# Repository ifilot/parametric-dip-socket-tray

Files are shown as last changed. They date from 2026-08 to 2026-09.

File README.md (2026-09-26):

# Parametric DIP and PLCC socket trays





Stackable 160 × 160 mm storage trays for standard spring-contact DIP sockets and
MPE M-PLCC 32 T and M-PLCC 44 T through-hole sockets. The DIP trays use
continuous channels; the PLCC trays use individual pin-protecting positions. All
trays share the same interlocking interface and universal lid.

## Features

- Eight supported DIP profiles, including slim and wide DIP-28 sockets
- Dedicated PLCC32 and PLCC44 trays with pin-protecting positions
- Automatic selection of narrow 300 mil or wide 600 mil geometry
- Central support ridges keep the socket pins above the tray floor
- Capacity calculated automatically from the socket dimensions
- Common interlocking interface allows every tray size to stack together
- Universal stackable lid fits every tray size
- 2 mm clearance above stored sockets in a stack
- Recessed size labels with optional two-colour inlays
- Ready-to-print STLs and small fit-test coupons
- Fully parametric OpenSCAD source

## Downloads

**[Download the parametric OpenSCAD
source](https://raw.githubusercontent.com/ifilot/parametric-dip-socket-tray/master/dip_socket_tray.scad)**
· **[Download the complete
project](https://github.com/ifilot/parametric-dip-socket-tray/archive/refs/heads/master.zip)**
· **[Download versioned
releases](https://github.com/ifilot/parametric-dip-socket-tray/releases)** ·
**[View automated
builds](https://github.com/ifilot/parametric-dip-socket-tray/actions/workflows/build-trays.yml)**

**[Download the universal lid
STL](https://raw.githubusercontent.com/ifilot/parametric-dip-socket-tray/master/exports/dip-socket-tray-lid.stl)**

| Socket | Tray | Two-colour label | Fit test |
| --- | --- | --- | --- |
| DIP-14 | [Download STL](https://raw.githubusercontent.com/ifilot/parametric-dip-socket-tray/master/exports/dip14-tray.stl) | [Download label](https://raw.githubusercontent.com/ifilot/parametric-dip-socket-tray/master/exports/dip14-label.stl) | [Download test](https://raw.githubusercontent.com/ifilot/parametric-dip-socket-tray/master/exports/dip14-fit-test.stl) |
| DIP-16 | [Download STL](https://raw.githubusercontent.com/ifilot/parametric-dip-socket-tray/master/exports/dip16-tray.stl) | [Download label](https://raw.githubusercontent.com/ifilot/parametric-dip-socket-tray/master/exports/dip16-label.stl) | [Download test](https://raw.githubusercontent.com/ifilot/parametric-dip-socket-tray/master/exports/dip16-fit-test.stl) |
| DIP-18 | [Download STL](https://raw.githubusercontent.com/ifilot/parametric-dip-socket-tray/master/exports/dip18-tray.stl) | [Download label](https://raw.githubusercontent.com/ifilot/parametric-dip-socket-tray/master/exports/dip18-label.stl) | [Download test](https://raw.githubusercontent.com/ifilot/parametric-dip-socket-tray/master/exports/dip18-fit-test.stl) |
| DIP-20 | [Download STL](https://raw.githubusercontent.com/ifilot/parametric-dip-socket-tray/master/exports/dip20-tray.stl) | [Download label](https://raw.githubusercontent.com/ifilot/parametric-dip-socket-tray/master/exports/dip20-label.stl) | [Download test](https://raw.githubusercontent.com/ifilot/parametric-dip-socket-tray/master/exports/dip20-fit-test.stl) |
| DIP-28 wide | [Download STL](https://raw.githubusercontent.com/ifilot/parametric-dip-socket-tray/master/exports/dip28-tray.stl) | [Download label](https://raw.githubusercontent.com/ifilot/parametric-dip-socket-tray/master/exports/dip28-label.stl) | [Download test](https://raw.githubusercontent.com/ifilot/parametric-dip-socket-tray/master/exports/dip28-fit-test.stl) |
| DIP-32 wide | [Download STL](https://raw.githubusercontent.com/ifilot/parametric-dip-socket-tray/master/exports/dip32-tray.stl) | [Download label](https://raw.githubusercontent.com/ifilot/parametric-dip-socket-tray/master/exports/dip32-label.stl) | [Download test](https://raw.githubusercontent.com/ifilot/parametric-dip-socket-tray/master/exports/dip32-fit-test.stl) |
| DIP-40 wide | [Download STL](https://raw.githubusercontent.com/ifilot/parametric-dip-socket-tray/master/exports/dip40-tray.stl) | [Download label](https://raw.githubusercontent.com/ifilot/parametric-dip-socket-tray/master/exports/dip40-label.stl) | [Download test](https://raw.githubusercontent.com/ifilot/parametric-dip-socket-tray/master/exports/dip40-fit-test.stl) |
| DIP-28 slim | [Download STL](https://raw.githubusercontent.com/ifilot/parametric-dip-socket-tray/master/exports/dip28-slim-tray.stl) | [Download label](https://raw.githubusercontent.com/ifilot/parametric-dip-socket-tray/master/exports/dip28-slim-label.stl) | [Download test](https://raw.githubusercontent.com/ifilot/parametric-dip-socket-tray/master/exports/dip28-slim-fit-test.stl) |
| PLCC-32 socket | [Download STL](https://raw.githubusercontent.com/ifilot/parametric-dip-socket-tray/master/exports/plcc32-socket-tray.stl) | [Download label](https://raw.githubusercontent.com/ifilot/parametric-dip-socket-tray/master/exports/plcc32-socket-label.stl) | [Download test](https://raw.githubusercontent.com/ifilot/parametric-dip-socket-tray/master/exports/plcc32-socket-fit-test.stl) |
| PLCC-44 socket | [Download STL](https://raw.githubusercontent.com/ifilot/parametric-dip-socket-tray/master/exports/plcc44-socket-tray.stl) | [Download label](https://raw.githubusercontent.com/ifilot/parametric-dip-socket-tray/master/exports/plcc44-socket-label.stl) | [Download test](https://raw.githubusercontent.com/ifilot/parametric-dip-socket-tray/master/exports/plcc44-socket-fit-test.stl) |

## Tray previews

| DIP-14 — 104 sockets | DIP-16 — 91 sockets |
| --- | --- |
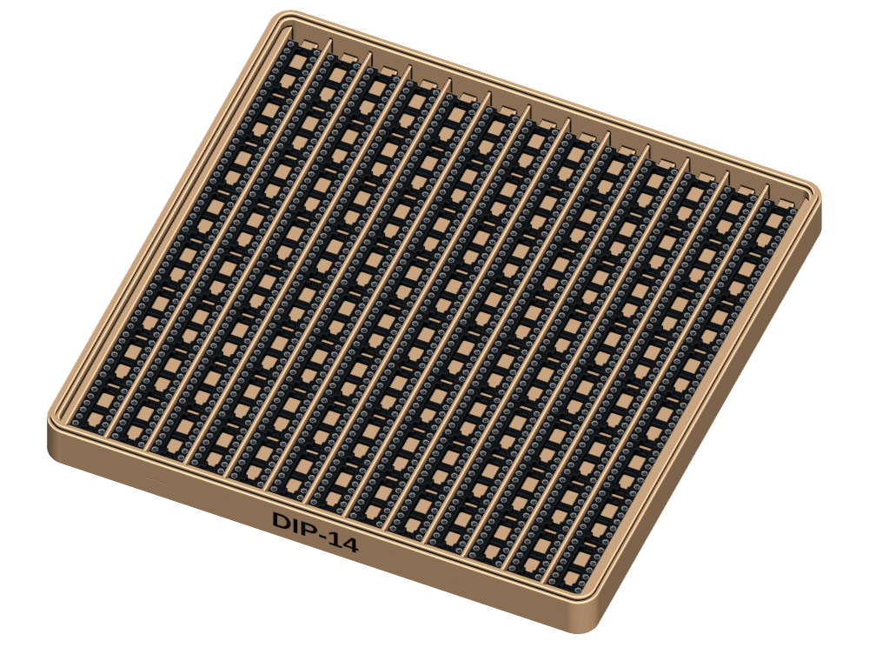
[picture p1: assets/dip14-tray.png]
DIP-14 tray
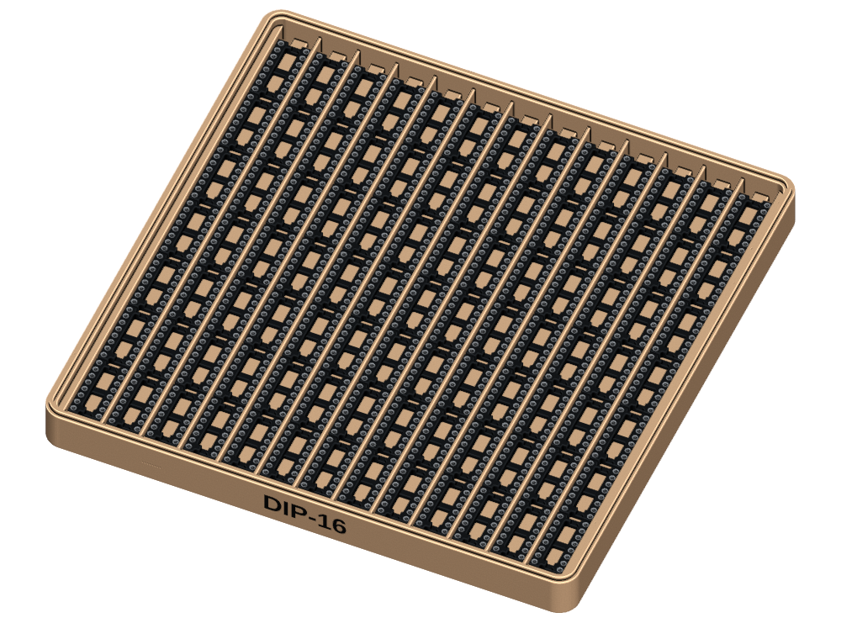
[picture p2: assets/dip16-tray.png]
DIP-16 tray
|  |  |

| DIP-18 — 78 sockets | DIP-20 — 65 sockets |
| --- | --- |
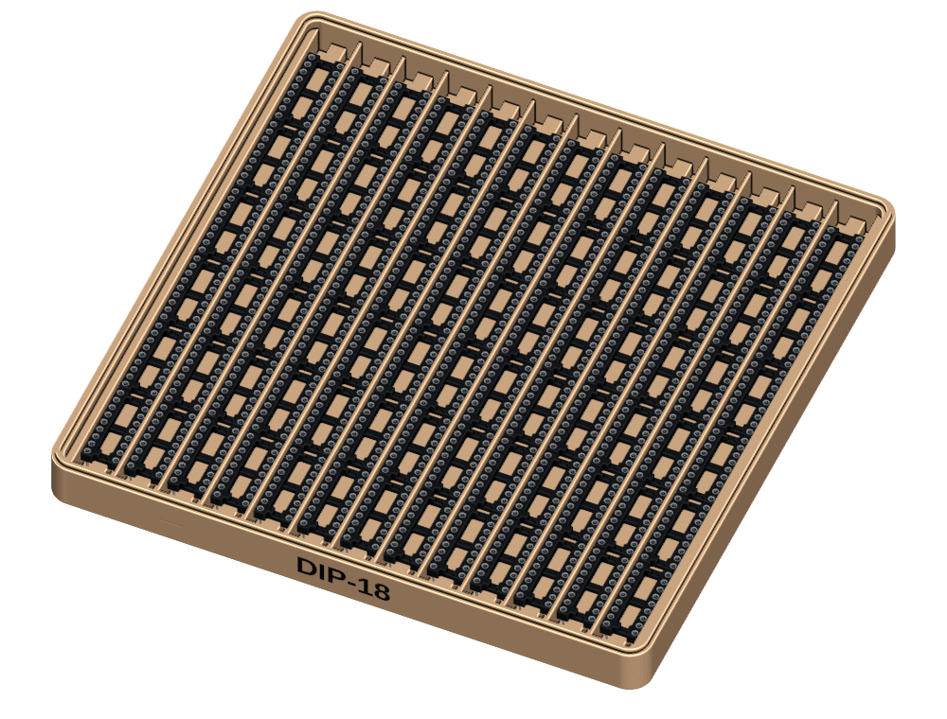
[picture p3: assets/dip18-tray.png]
DIP-18 tray
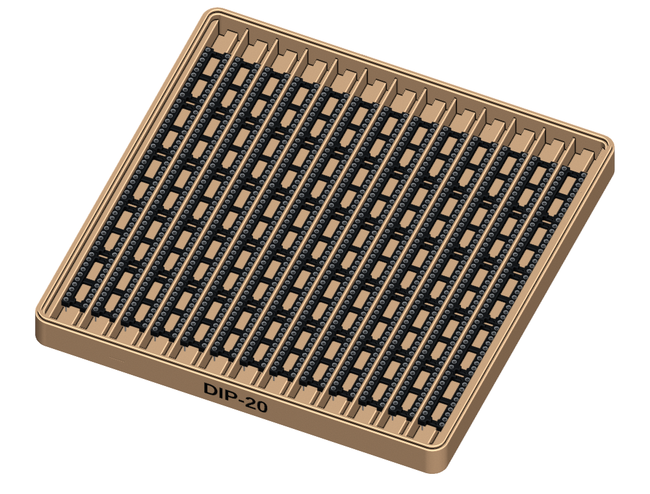
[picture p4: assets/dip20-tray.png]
DIP-20 tray
|  |  |

| DIP-28 wide — 32 sockets | DIP-32 wide — 24 sockets |
| --- | --- |
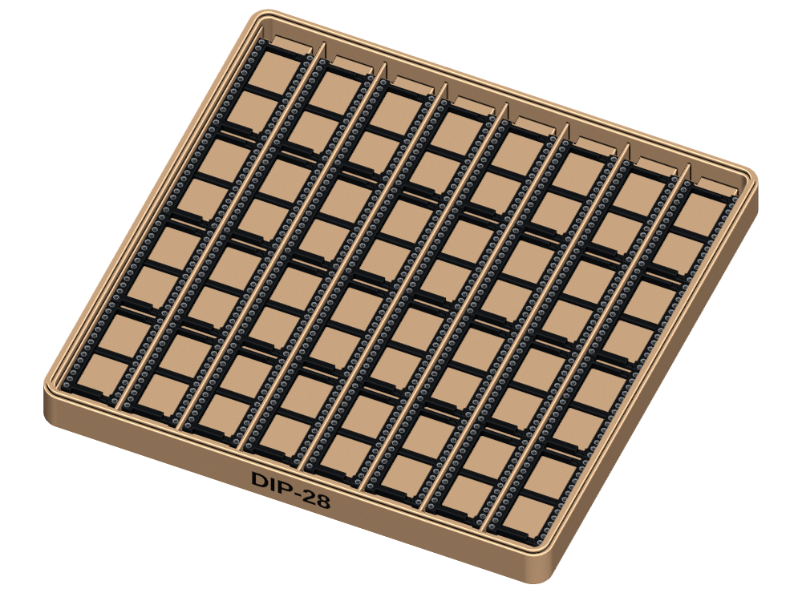
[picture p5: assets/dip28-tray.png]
Wide DIP-28 tray
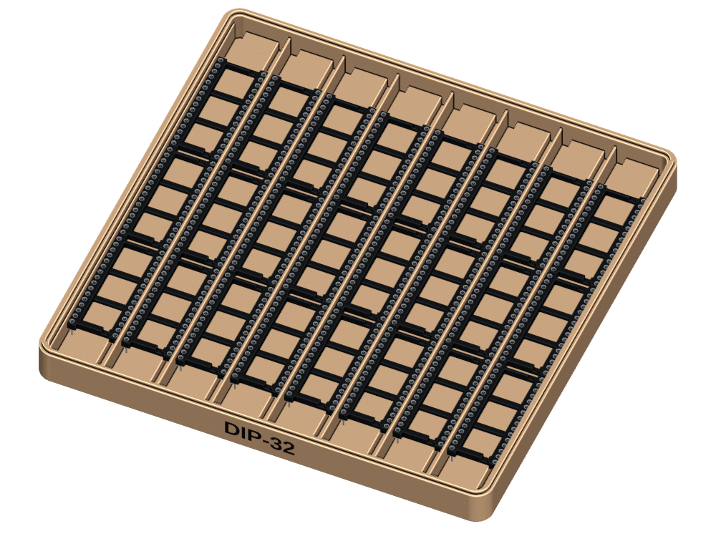
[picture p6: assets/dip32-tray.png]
Wide DIP-32 tray
|  |  |

| DIP-40 wide — 24 sockets |
| --- |
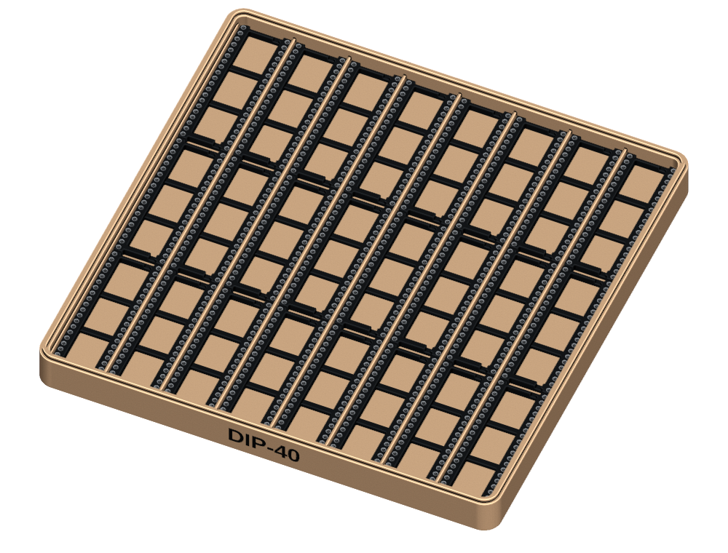
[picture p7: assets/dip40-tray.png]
Wide DIP-40 tray
|  |

| DIP-28 slim — 52 sockets | PLCC-44 socket — 36 sockets |
| --- | --- |
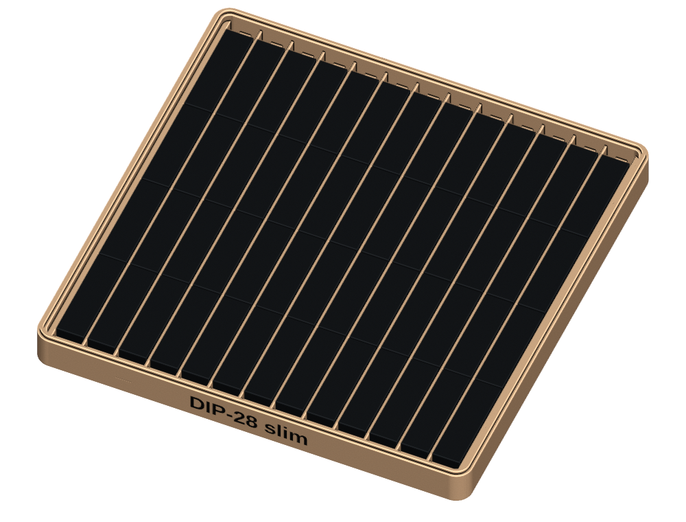
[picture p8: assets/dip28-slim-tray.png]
Slim DIP-28 tray
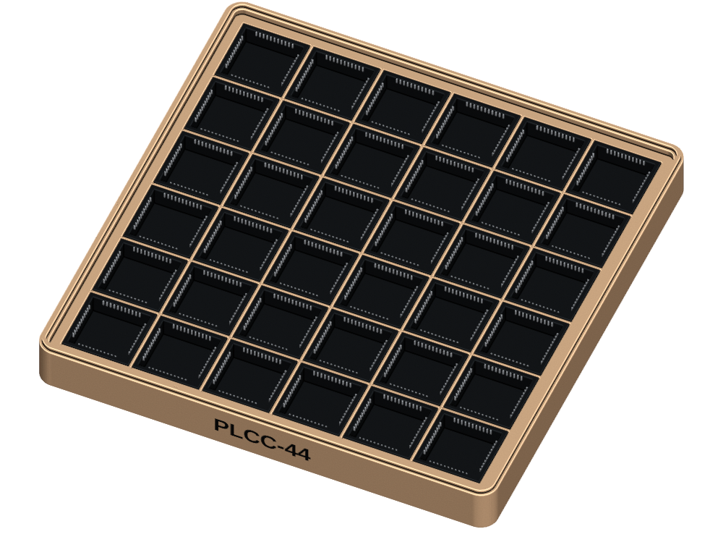
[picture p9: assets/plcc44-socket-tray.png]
PLCC-44 socket tray
|  |  |

| PLCC-32 socket — 49 sockets |
| --- |
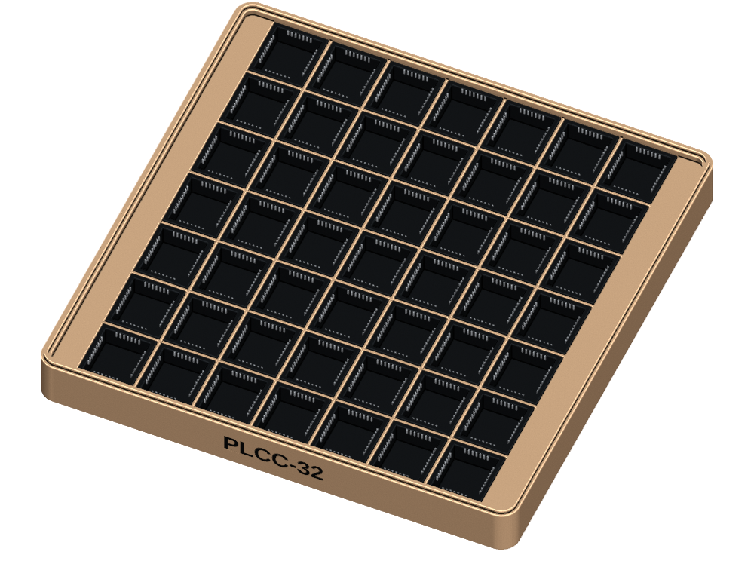
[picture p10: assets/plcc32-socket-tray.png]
PLCC-32 socket tray
|  |

The DIP socket geometry shown in the previews is derived from the [KiCad 3D
Models library](https://gitlab.com/kicad/libraries/kicad-packages3D), licensed
under [CC BY-SA 4.0 with the KiCad Libraries
Exception](https://www.kicad.org/libraries/license/). The PLCC32 and PLCC44
previews use simplified procedural models based on the MPE socket drawing. The
sockets are shown for illustration only and are not included in the downloadable
tray models.

## Supported trays

| Socket | Profile | Rows | Per row | Capacity |
| --- | --- | ---: | ---: | ---: |
| DIP-14 | 300 mil | 13 | 8 | 104 |
| DIP-16 | 300 mil | 13 | 7 | 91 |
| DIP-18 | 300 mil | 13 | 6 | 78 |
| DIP-20 | 300 mil | 13 | 5 | 65 |
| DIP-28 slim | 300 mil | 13 | 4 | 52 |
| DIP-28 wide | 600 mil | 8 | 4 | 32 |
| DIP-32 | 600 mil | 8 | 3 | 24 |
| DIP-40 | 600 mil | 8 | 3 | 24 |
| PLCC-32 socket | MPE series 300 | 7 | 7 | 49 |
| PLCC-44 socket | MPE series 300 | 6 | 6 | 36 |

Sockets lie end-to-end in long channels. Their plastic bodies rest on a central
ridge while both pin rows float in continuous trenches. The channel guides rise
4.2 mm above the support surface to keep sockets aligned.

The validated profiles use:

| Dimension | Narrow sockets | Wide sockets |
| --- | ---: | ---: |
| Pin-row spacing | 7.62 mm | 15.24 mm |
| Overall socket width | 10.16 mm | 17.78 mm |
| Central support ridge | 4.0 mm | 11.5 mm |

Socket length is derived from the 2.54 mm pin pitch and selected pin count.

The PLCC32 and PLCC44 models are based on the MPE series-300 entries in the [MPE
series-300
datasheet](https://cdn-reichelt.de/documents/datenblatt/C100/PLCC20_PLCC28_PLCC32_PLCC44~MPE.pdf).
Each socket rests on a central island while all four pin rows hang freely above
the tray floor. Shared guides keep the sockets separated and rise to
approximately the top of each socket body.

| PLCC socket dimension | PLCC32 | PLCC44 |
| --- | ---: | ---: |
| Body size (`B`) | 18.10 × 20.64 mm | 23.18 × 23.18 mm |
| Pin-row spacing (`D`) | 12.70 × 15.24 mm | 17.78 × 17.78 mm |
| Outer pin span (`A`) | 7.62 × 10.16 mm | 12.70 × 12.70 mm |
| Body height | 8.30 mm | 8.30 mm |
| Pin drop | 3.70 mm | 3.70 mm |
| Clear support footprint | 6.00 × 8.00 mm | 11.00 × 11.00 mm |
| Support height above tray floor | 4.00 mm | 4.00 mm |
| Guide height above support | 8.00 mm | 8.00 mm |

Dimension `D` is the PCB hole-row spacing; it does not specify the minimum clear
opening between the bent portions of the socket pins. The support footprints are
kept inside the nominal `A` pin spans. Their 4 mm height leaves 0.30 mm between
the nominal 3.70 mm pin tips and the tray floor. Print the fit test for the
exact socket before committing to the complete tray.

## Using the OpenSCAD model

Open `dip_socket_tray.scad` and set `pins` to one of:

```text
14, 16, 18, 20, 28, 32, 40
```

For the narrow 300 mil DIP-28 profile, also set `socket_profile = "narrow"`.

The profile is selected automatically by default; set `socket_profile` to
`narrow` for the slim DIP-28 tray. Use `part` to choose the output:

- `assembly` — preview the tray, contrasting label, and reference sockets
- `tray` — printable tray with recessed lettering
- `lid` — universal lid with a tray-compatible groove and stacking lip
- `label` — separate label inlay for two-colour printing
- `fit_test` — short channel for checking socket fit and pin clearance

The model prints the calculated tray capacity or lid dimensions in OpenSCAD's
console. Ready-to-print lid, tray, label, and fit-test STLs are available in
`exports/`.

For the PLCC socket trays, open `plcc32_socket_tray.scad` or
`plcc44_socket_tray.scad`. Each provides the same `part` choices and uses the
same stacking interface. Export it directly with, for example:

```sh
openscad -o plcc44-socket-tray.stl -D 'part="tray"' plcc44_socket_tray.scad
```

## Fit and customization

The DIP fit tests, including the slim DIP-28 profile, have been physically
verified with the intended socket styles. The PLCC44 fit test has also been
physically verified. The PLCC32 outer fit has been tested, while its revised
support island should still be confirmed with its fit test before printing the
complete tray. This is especially important for other socket brands or
constructions.

Useful parameters include:

- `narrow_socket_width`, `wide_socket_width`, and `side_clearance`
- `pin_drop` and `pin_clearance`
- `narrow_support_ridge_width` and `wide_support_ridge_width`
- `socket_height` and `vertical_clearance`
- `stack_fit` and `stack_groove_depth`
- `lid_thickness`

The PLCC32 and PLCC44 models additionally expose `socket_size`,
`pin_row_spacing`, `pin_span`, `support_size`, `support_height`, and its
independent guide clearances. Print the appropriate PLCC fit test before
committing to the complete tray, especially when using a socket from a different
manufacturer.

## Printing

Suggested PLA settings:

- 0.25 mm layer height
- Three perimeters
- 15–20% infill
- No supports

The printer must provide a build area of at least 160 × 160 mm.

## Building all parts

With OpenSCAD available on the command line, generate the universal lid plus all
30 tray, label, and fit-test STLs with:

```sh
bash scripts/build_all.sh
```

Output is written to `build/` by default. Pass a directory as the first argument
to use a different destination. GitHub Actions runs the same script for pushes
and pull requests that affect the model or build procedure, then publishes the
complete STL set as a downloadable workflow artifact.

## Versioning and releases

This project follows [Semantic Versioning](https://semver.org/). The current
version is recorded in [`VERSION`](VERSION), and release notes are maintained in
[`CHANGELOG.md`](CHANGELOG.md).

## Stacking interface

Every variant uses the same perimeter lip and underside groove:

| Feature | Dimension |
| --- | ---: |
| Lip width | 1.20 mm |
| Lip height | 1.20 mm |
| Groove width | 1.80 mm |
| Groove depth | 1.40 mm |
| Horizontal clearance | 0.30 mm per side |
| Vertical clearance inside groove | 0.20 mm |

The groove locates the upper tray while perimeter ledges carry its weight, so
the lip does not bottom out. All socket sizes can be stacked in any order. The
universal lid uses the same groove underneath and repeats the lip on top, so it
can cap a stack or sit between trays without breaking compatibility.

Export the lid directly with:

```sh
openscad -o dip-socket-tray-lid.stl -D 'part="lid"' dip_socket_tray.scad
```

## Two-colour labels

Export the tray and label separately:

```sh
openscad -o dip14-tray.stl -D 'pins=14' -D 'part="tray"' dip_socket_tray.scad
openscad -o dip14-label.stl -D 'pins=14' -D 'part="label"' dip_socket_tray.scad
```

Import the matching tray and label STLs into a multi-material slicer as parts of
the same object. Keep both at their original coordinates, then assign each part
to the desired material or colour. Do not auto-arrange the parts separately.

For single-colour printing, export only `tray`; the label remains recessed.

## License

This open hardware design is licensed under the CERN Open Hardware Licence
Version 2 — Strongly Reciprocal (`CERN-OHL-S-2.0`). You may use, modify,
manufacture, and sell products based on it under the terms in `LICENSE`.
Distributed modifications and products must retain the required notices and make
the corresponding complete source available.

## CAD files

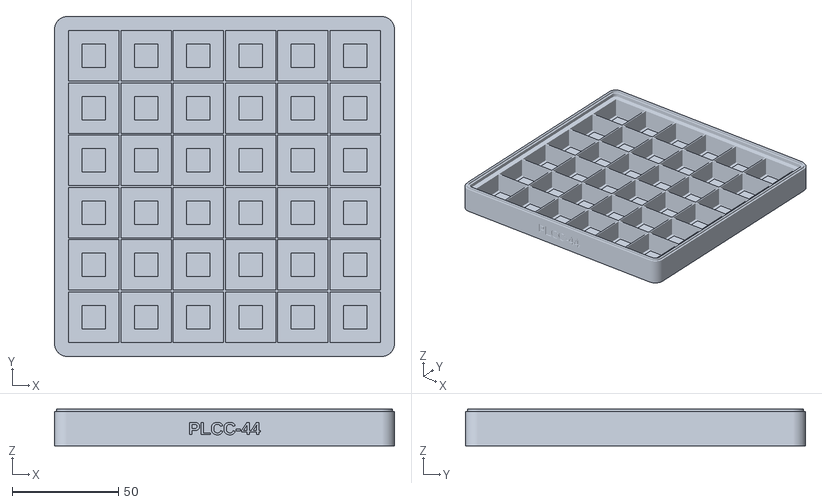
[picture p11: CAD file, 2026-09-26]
exports/plcc44-socket-tray.stl
160.0 x 160.0 x 17.3

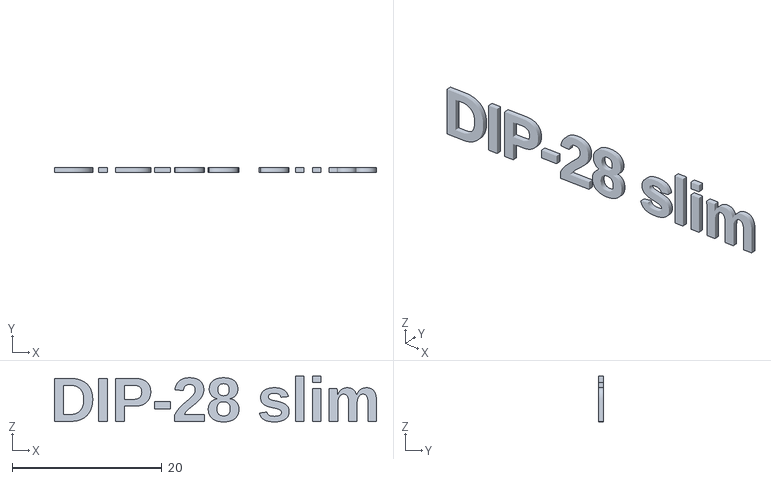
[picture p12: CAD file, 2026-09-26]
exports/dip28-slim-label.stl
43.0 x 0.62 x 6.12

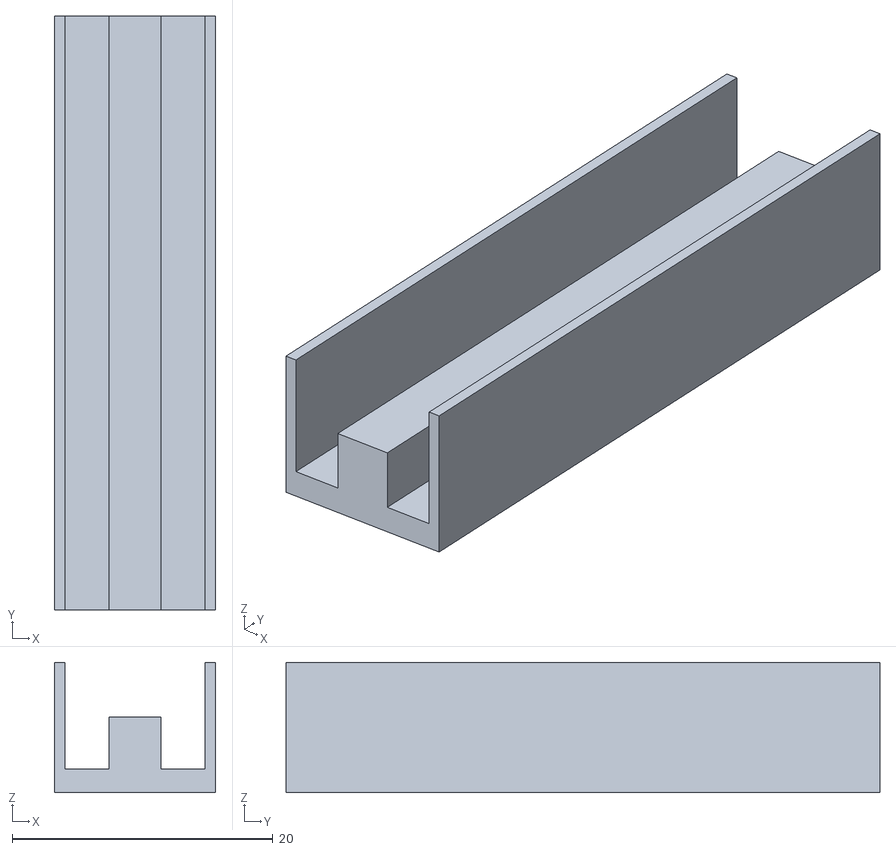
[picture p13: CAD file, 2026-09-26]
exports/dip28-slim-fit-test.stl
12.4 x 45.6 x 10.0

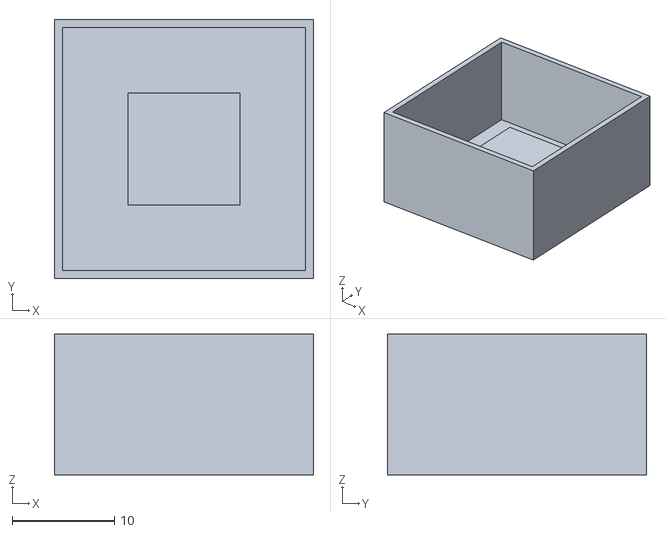
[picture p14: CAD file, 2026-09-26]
exports/plcc44-socket-fit-test.stl
25.4 x 25.4 x 13.8

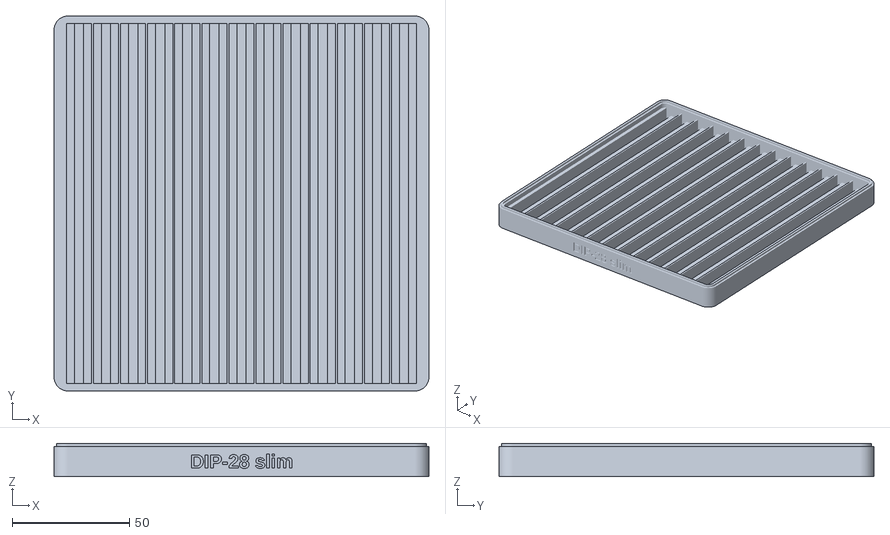
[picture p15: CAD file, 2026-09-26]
exports/dip28-slim-tray.stl
160.0 x 160.0 x 14.1

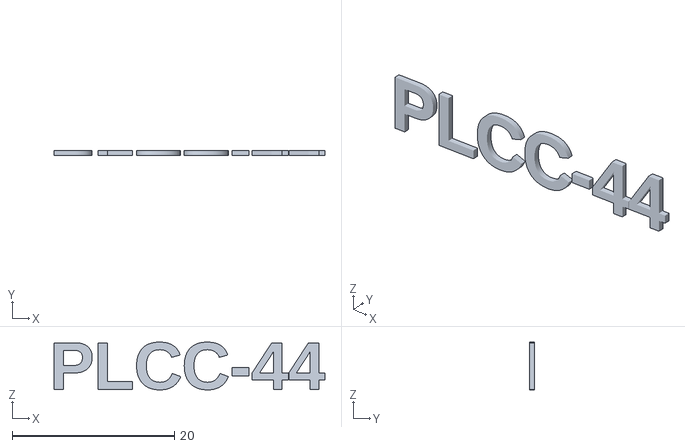
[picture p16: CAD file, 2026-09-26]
exports/plcc44-socket-label.stl
33.4 x 0.62 x 5.90

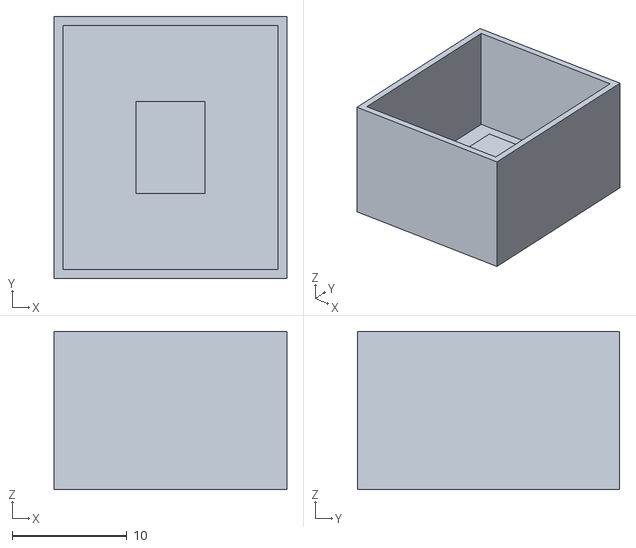
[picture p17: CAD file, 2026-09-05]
exports/plcc32-socket-fit-test.stl
20.3 x 22.8 x 13.8

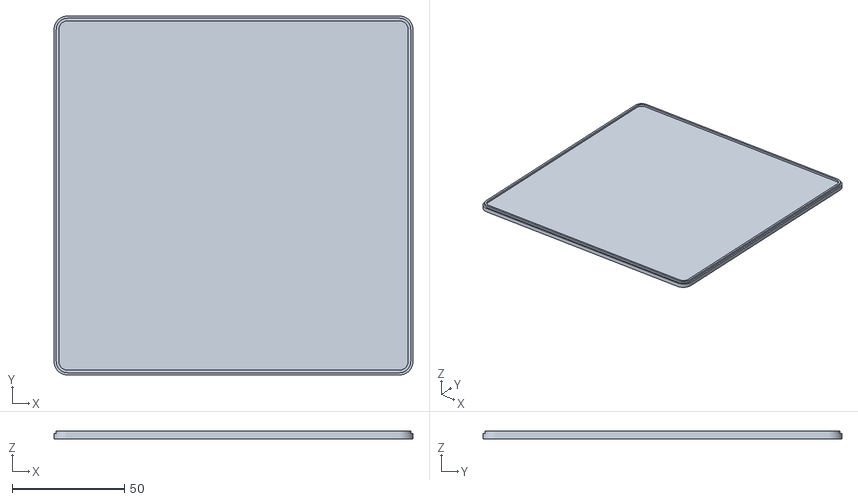
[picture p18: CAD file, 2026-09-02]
exports/dip-socket-tray-lid.stl
160.0 x 160.0 x 3.60

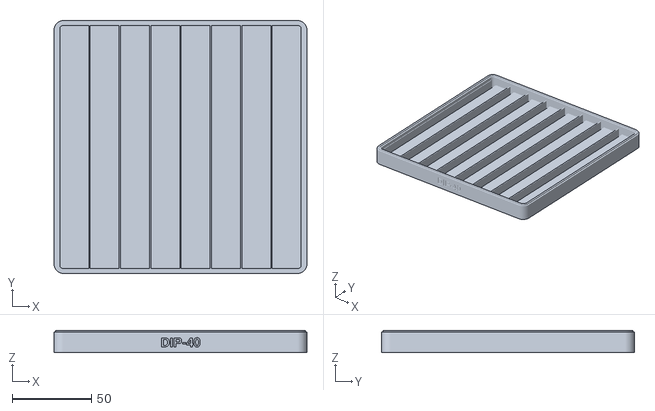
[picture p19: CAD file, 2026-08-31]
exports/dip40-tray.stl
160.0 x 160.0 x 14.1

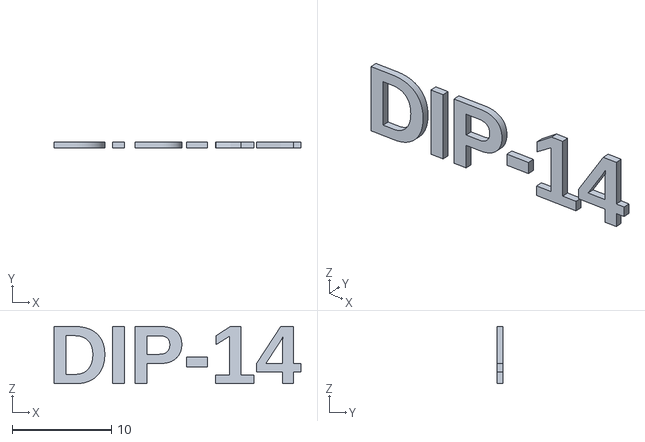
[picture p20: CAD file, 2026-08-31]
exports/dip14-label.stl
24.8 x 0.62 x 5.73

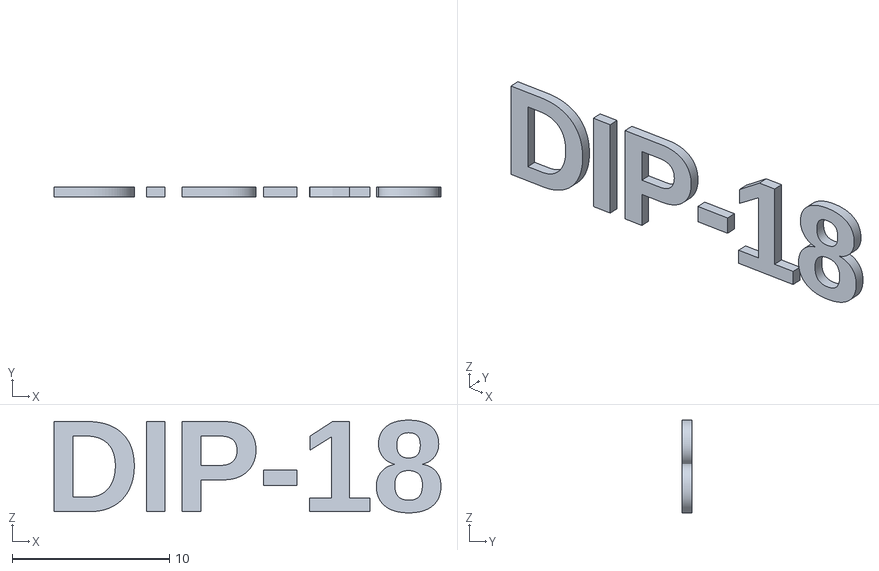
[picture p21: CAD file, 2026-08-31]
exports/dip18-label.stl
24.6 x 0.62 x 5.90

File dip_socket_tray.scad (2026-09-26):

// SPDX-License-Identifier: CERN-OHL-S-2.0

/*
 * Parametric stackable tray for inexpensive 300/600 mil DIP sockets.
 * Designed for FDM printing, with a common 160 x 160 mm stacking interface.
 *
 * Export examples:
 *   openscad -o dip14-tray.stl -D 'pins=14' -D 'part="tray"' dip_socket_tray.scad
 *   openscad -o lid.stl        -D 'part="lid"' dip_socket_tray.scad
 *   openscad -o dip14-label.stl -D 'pins=14' -D 'part="label"' dip_socket_tray.scad
 *   openscad -o fit-test.stl   -D 'part="fit_test"' dip_socket_tray.scad
 */

/* [Main] */
pins = 14;                    // [14,16,18,20,28,32,40]
socket_profile = "auto";      // [auto,narrow,wide]
part = "assembly";            // [assembly,tray,lid,label,fit_test]
show_sockets = true;          // Preview-only reference sockets

/* [Socket] */
narrow_socket_width = 10.16;  // Overall width for 300 mil sockets
wide_socket_width = 17.78;    // Overall width for 600 mil sockets
socket_height = 5.10;         // Body height above its underside
pin_pitch = 2.54;
narrow_row_spacing = 7.62;
wide_row_spacing = 15.24;
pin_drop = 3.60;              // Conservative pins-below-body allowance
pin_clearance = 0.40;         // Free space below pin tips
side_clearance = 0.30;        // Body-to-guide clearance per side
socket_end_gap = 0.60;        // Gap between sockets in a row
narrow_support_ridge_width = 4.00;
wide_support_ridge_width = 11.50;

/* [Tray] */
tray_size = [160, 160];
base_thickness = 1.80;
outer_wall = 3.20;
corner_radius = 6;
guide_width = 0.80;
guide_height = 4.20;          // Guide height above body support
vertical_clearance = 2.00;    // Socket top to the next tray bottom

/* [Stacking interface] */
stack_lip_width = 1.20;
stack_lip_height = 1.20;
stack_fit = 0.30;             // Horizontal clearance on each side
stack_groove_depth = 1.40;
stack_inset = 1.00;

/* [Lid] */
lid_thickness = 2.40;

/* [Label] */
label_depth = 0.60;
label_height = 6.0;
label_font = "Liberation Sans:style=Bold";

/* [Quality] */
$fn = $preview ? 40 : 80;

eps = 0.01;
valid_pins = pins == 14 || pins == 16 || pins == 18 || pins == 20
          || pins == 28 || pins == 32 || pins == 40;
valid_socket_profile = socket_profile == "auto"
                    || socket_profile == "narrow"
                    || socket_profile == "wide";
is_wide_socket = socket_profile == "wide"
              || (socket_profile == "auto"
                  && (pins == 28 || pins == 32 || pins == 40));
socket_width = is_wide_socket ? wide_socket_width : narrow_socket_width;
pin_row_spacing = is_wide_socket ? wide_row_spacing : narrow_row_spacing;
support_ridge_width = is_wide_socket
                    ? wide_support_ridge_width
                    : narrow_support_ridge_width;
socket_length = pins / 2 * pin_pitch;
support_z = base_thickness + pin_drop + pin_clearance;
stack_plane_z = support_z + socket_height + vertical_clearance;
label_z = stack_plane_z / 2;
channel_width = socket_width + 2 * side_clearance;
row_pitch = channel_width + guide_width;
inner_size = [tray_size[0] - 2 * outer_wall,
              tray_size[1] - 2 * outer_wall];
row_count = floor((inner_size[0] + guide_width) / row_pitch);
socket_count_per_row = floor((inner_size[1] + socket_end_gap) /
                             (socket_length + socket_end_gap));
used_rows_width = row_count * channel_width + (row_count - 1) * guide_width;
rows_x0 = (tray_size[0] - used_rows_width) / 2;
used_socket_length = socket_count_per_row * socket_length
                   + (socket_count_per_row - 1) * socket_end_gap;
sockets_y0 = (tray_size[1] - used_socket_length) / 2;
label_text = pins == 28 && socket_profile == "narrow"
           ? "DIP-28 slim"
           : str("DIP-", pins);

assert(valid_pins, "pins must be 14, 16, 18, 20, 28, 32, or 40");
assert(valid_socket_profile,
       "socket_profile must be auto, narrow, or wide");
assert(base_thickness > stack_groove_depth,
       "The stacking groove must leave some base thickness");
assert(lid_thickness > stack_groove_depth,
       "The stacking groove must leave some lid thickness");
assert(support_ridge_width < pin_row_spacing - 1.0,
       "Support ridge is too wide and may contact inward-bent pins");
assert(row_count > 0 && socket_count_per_row > 0,
       "Socket dimensions leave no usable storage positions");

if (part == "lid") {
    echo(str("Universal lid: ", tray_size[0], " x ", tray_size[1],
             " x ", lid_thickness + stack_lip_height, " mm"));
} else {
    echo(str(label_text, ": ", row_count, " rows x ",
             socket_count_per_row, " sockets = ",
             row_count * socket_count_per_row, " sockets"));
    echo(str("Stacking pitch: ", stack_plane_z,
             " mm; overall printed height: ",
             stack_plane_z + stack_lip_height, " mm"));
}

module rounded_rect_2d(size, radius) {
    offset(r = radius)
        square([size[0] - 2 * radius, size[1] - 2 * radius], center = true);
}

module rounded_ring_2d(outer_size, width, radius) {
    difference() {
        rounded_rect_2d(outer_size, radius);
        rounded_rect_2d([outer_size[0] - 2 * width,
                         outer_size[1] - 2 * width],
                        max(radius - width, 0.01));
    }
}

module tray_base(thickness = base_thickness) {
    translate([tray_size[0] / 2, tray_size[1] / 2, 0])
        linear_extrude(thickness)
            rounded_rect_2d(tray_size, corner_radius);
}

module perimeter_wall() {
    translate([tray_size[0] / 2, tray_size[1] / 2,
               base_thickness - eps])
        linear_extrude(stack_plane_z - base_thickness + 2 * eps)
            rounded_ring_2d(tray_size, outer_wall, corner_radius);
}

module stack_lip(z = stack_plane_z) {
    lip_outer = [tray_size[0] - 2 * stack_inset,
                 tray_size[1] - 2 * stack_inset];
    translate([tray_size[0] / 2, tray_size[1] / 2,
               z - eps])
        linear_extrude(stack_lip_height + eps)
            rounded_ring_2d(lip_outer, stack_lip_width,
                            corner_radius - stack_inset);
}

module stack_groove_cut() {
    groove_outer = [tray_size[0] - 2 * (stack_inset - stack_fit),
                    tray_size[1] - 2 * (stack_inset - stack_fit)];
    groove_width = stack_lip_width + 2 * stack_fit;
    translate([tray_size[0] / 2, tray_size[1] / 2, -eps])
        linear_extrude(stack_groove_depth + eps)
            rounded_ring_2d(groove_outer, groove_width,
                            corner_radius - stack_inset + stack_fit);
}

module storage_rails() {
    // Each socket bridges two uninterrupted pin trenches and rests only on
    // the central dike. Guides on both sides of every channel keep the bodies
    // upright. The outer guides extend to the perimeter, leaving no debris-
    // collecting gap while retaining the same channel-facing clearance.
    for (row = [0 : row_count - 1]) {
        cx = rows_x0 + channel_width / 2 + row * row_pitch;

        translate([cx - support_ridge_width / 2, outer_wall,
                   base_thickness - eps])
            cube([support_ridge_width, inner_size[1],
                  support_z - base_thickness + eps]);
    }

    for (divider = [1 : row_count - 1]) {
        x = rows_x0 + divider * channel_width
          + (divider - 1) * guide_width;
        translate([x, outer_wall, base_thickness - eps])
            cube([guide_width, inner_size[1],
                  support_z + guide_height - base_thickness + eps]);
    }

    edge_guide_width = rows_x0 - outer_wall;
    for (x = [outer_wall, rows_x0 + used_rows_width])
        translate([x, outer_wall, base_thickness - eps])
            cube([edge_guide_width, inner_size[1],
                  support_z + guide_height - base_thickness + eps]);
}

module front_label(depth = label_depth + 2 * eps) {
    // Text lies on the outside of the front wall. Rotating about X maps the
    // text extrusion into Y, leaving Z as the readable vertical direction.
    translate([tray_size[0] / 2, depth - eps, label_z])
        rotate([90, 0, 0])
            linear_extrude(depth)
                text(label_text, size = label_height, font = label_font,
                     halign = "center", valign = "center");
}

module tray() {
    difference() {
        union() {
            tray_base();
            perimeter_wall();
            storage_rails();
            stack_lip();
        }
        stack_groove_cut();
        front_label();
    }
}

module lid() {
    // The underside groove fits every tray's top lip. Repeating the lip on
    // top keeps the complete system stackable even when the lid is inserted
    // between trays.
    difference() {
        union() {
            tray_base(lid_thickness);
            stack_lip(lid_thickness);
        }
        stack_groove_cut();
    }
}

module label_inlay() {
    // Export as a second STL and load it as another part of the same object
    // in PrusaSlicer. It occupies exactly the volume removed from the tray.
    front_label();
}
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

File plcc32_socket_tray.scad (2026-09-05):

// SPDX-License-Identifier: CERN-OHL-S-2.0

/*
 * Stackable tray for MPE series-300 PLCC32 through-hole sockets.
 * The socket dimensions are taken from the M-PLCC 32 T datasheet.
 * Uses the same 160 x 160 mm stacking interface as dip_socket_tray.scad.
 *
 * Export examples:
 *   openscad -o plcc32-socket-tray.stl -D 'part="tray"' plcc32_socket_tray.scad
 *   openscad -o plcc32-socket-label.stl -D 'part="label"' plcc32_socket_tray.scad
 *   openscad -o plcc32-socket-fit-test.stl -D 'part="fit_test"' plcc32_socket_tray.scad
 */

/* [Main] */
part = "assembly";            // [assembly,tray,lid,label,fit_test]
show_sockets = true;          // Preview-only reference sockets

/* [PLCC32 socket] */
socket_size = [18.10, 20.64]; // Datasheet dimension B (width x length)
socket_height = 8.30;
pin_drop = 3.70;
side_clearance = 0.30;       // Body-to-guide clearance per side
pin_pitch = 1.27;
pin_row_spacing = [12.70, 15.24]; // PCB hole-row spacing, datasheet dimension D
pin_span = [7.62, 10.16];         // Datasheet dimension A
pin_width = 0.48;
support_size = [6.00, 8.00]; // Fits inside the socket's bent pins
support_height = 4.00;       // Height above the tray floor

/* [Tray] */
tray_size = [160, 160];
base_thickness = 1.80;
outer_wall = 3.20;
corner_radius = 6;
guide_width = 0.80;
guide_height = 8.00;         // Guide height above the body support
vertical_clearance = 2.00;   // Socket top to the next tray bottom

/* [Stacking interface] */
stack_lip_width = 1.20;
stack_lip_height = 1.20;
stack_fit = 0.30;
stack_groove_depth = 1.40;
stack_inset = 1.00;

/* [Lid] */
lid_thickness = 2.40;

/* [Label] */
label_depth = 0.60;
label_height = 6.0;
label_font = "Liberation Sans:style=Bold";

/* [Quality] */
$fn = $preview ? 40 : 80;

eps = 0.01;
pin_clearance = support_height - pin_drop;
support_z = base_thickness + support_height;
stack_plane_z = support_z + socket_height + vertical_clearance;
label_z = stack_plane_z / 2;
cell_size = [socket_size[0] + 2 * side_clearance,
             socket_size[1] + 2 * side_clearance];
cell_pitch = [cell_size[0] + guide_width,
              cell_size[1] + guide_width];
inner_size = [tray_size[0] - 2 * outer_wall,
              tray_size[1] - 2 * outer_wall];
column_count = floor((inner_size[0] + guide_width) / cell_pitch[0]);
row_count = floor((inner_size[1] + guide_width) / cell_pitch[1]);
used_grid_size = [column_count * cell_size[0]
                  + (column_count - 1) * guide_width,
                  row_count * cell_size[1]
                  + (row_count - 1) * guide_width];
grid_origin = [(tray_size[0] - used_grid_size[0]) / 2,
               (tray_size[1] - used_grid_size[1]) / 2];
label_text = "PLCC-32";

assert(base_thickness > stack_groove_depth,
       "The stacking groove must leave some base thickness");
assert(lid_thickness > stack_groove_depth,
       "The stacking groove must leave some lid thickness");
assert(pin_clearance > 0,
       "The support must leave clearance below the socket pin tips");
assert(support_size[0] + pin_width < pin_row_spacing[0]
       && support_size[1] + pin_width < pin_row_spacing[1],
       "The support island may contact the socket pins");
assert(column_count > 0 && row_count > 0,
       "Socket dimensions leave no usable storage positions");

if (part == "lid") {
    echo(str("Universal lid: ", tray_size[0], " x ", tray_size[1],
             " x ", lid_thickness + stack_lip_height, " mm"));
} else {
    echo(str("PLCC-32 socket: ", column_count, " columns x ",
             row_count, " rows = ", column_count * row_count,
             " sockets"));
    echo(str("Stacking pitch: ", stack_plane_z,
             " mm; overall printed height: ",
             stack_plane_z + stack_lip_height, " mm"));
    echo(str("Support: ", support_size[0], " x ", support_size[1],
             " x ", support_height, " mm; pin-tip clearance: ",
             pin_clearance, " mm"));
}

module rounded_rect_2d(size, radius) {
    offset(r = radius)
        square([size[0] - 2 * radius, size[1] - 2 * radius], center = true);
}

module rounded_ring_2d(outer_size, width, radius) {
    difference() {
        rounded_rect_2d(outer_size, radius);
        rounded_rect_2d([outer_size[0] - 2 * width,
                         outer_size[1] - 2 * width],
                        max(radius - width, 0.01));
    }
}

module tray_base(thickness = base_thickness) {
    translate([tray_size[0] / 2, tray_size[1] / 2, 0])
        linear_extrude(thickness)
            rounded_rect_2d(tray_size, corner_radius);
}

module perimeter_wall() {
    translate([tray_size[0] / 2, tray_size[1] / 2,
               base_thickness - eps])
        linear_extrude(stack_plane_z - base_thickness + 2 * eps)
            rounded_ring_2d(tray_size, outer_wall, corner_radius);
}

module stack_lip(z = stack_plane_z) {
    lip_outer = [tray_size[0] - 2 * stack_inset,
                 tray_size[1] - 2 * stack_inset];
    translate([tray_size[0] / 2, tray_size[1] / 2, z - eps])
        linear_extrude(stack_lip_height + eps)
            rounded_ring_2d(lip_outer, stack_lip_width,
                            corner_radius - stack_inset);
}

module stack_groove_cut() {
    groove_outer = [tray_size[0] - 2 * (stack_inset - stack_fit),
                    tray_size[1] - 2 * (stack_inset - stack_fit)];
    groove_width = stack_lip_width + 2 * stack_fit;
    translate([tray_size[0] / 2, tray_size[1] / 2, -eps])
        linear_extrude(stack_groove_depth + eps)
            rounded_ring_2d(groove_outer, groove_width,
                            corner_radius - stack_inset + stack_fit);
}

module support_island(cx, cy) {
    translate([cx - support_size[0] / 2,
               cy - support_size[1] / 2,
               base_thickness - eps])
        cube([support_size[0], support_size[1],
              support_z - base_thickness + eps]);
}

module storage_pockets() {
    guide_top = support_z + guide_height;

    // One central island supports each socket body while all four rows of
    // through-hole pins hang freely around it.
    for (column = [0 : column_count - 1], row = [0 : row_count - 1]) {
        cx = grid_origin[0] + cell_size[0] / 2
           + column * cell_pitch[0];
        cy = grid_origin[1] + cell_size[1] / 2
           + row * cell_pitch[1];
        support_island(cx, cy);
    }

    // Shared walls locate every socket and rise to approximately the top of
    // the socket body.
    for (divider = [1 : column_count - 1]) {
        x = grid_origin[0] + divider * cell_size[0]
          + (divider - 1) * guide_width;
        translate([x, grid_origin[1], base_thickness - eps])
            cube([guide_width, used_grid_size[1],
                  guide_top - base_thickness + eps]);
    }

    for (divider = [1 : row_count - 1]) {
        y = grid_origin[1] + divider * cell_size[1]
          + (divider - 1) * guide_width;
        translate([grid_origin[0], y, base_thickness - eps])
            cube([used_grid_size[0], guide_width,
                  guide_top - base_thickness + eps]);
    }

    // Fill the margins up to the perimeter so the outermost positions have
    // the same body clearance as all internal positions.
    translate([outer_wall, outer_wall, base_thickness - eps])
        cube([grid_origin[0] - outer_wall, inner_size[1],
              guide_top - base_thickness + eps]);
    translate([grid_origin[0] + used_grid_size[0], outer_wall,
               base_thickness - eps])
        cube([tray_size[0] - outer_wall
              - grid_origin[0] - used_grid_size[0], inner_size[1],
              guide_top - base_thickness + eps]);
    translate([outer_wall, outer_wall, base_thickness - eps])
        cube([inner_size[0], grid_origin[1] - outer_wall,
              guide_top - base_thickness + eps]);
    translate([outer_wall, grid_origin[1] + used_grid_size[1],
               base_thickness - eps])
        cube([inner_size[0], tray_size[1] - outer_wall
              - grid_origin[1] - used_grid_size[1],
              guide_top - base_thickness + eps]);
}

module front_label(depth = label_depth + 2 * eps) {
    translate([tray_size[0] / 2, depth - eps, label_z])
        rotate([90, 0, 0])
            linear_extrude(depth)
                text(label_text, size = label_height, font = label_font,
                     halign = "center", valign = "center");
}

module tray() {
    difference() {
        union() {
            tray_base();
            perimeter_wall();
            storage_pockets();
            stack_lip();
        }
        stack_groove_cut();
        front_label();
    }
}

module lid() {
    difference() {
        union() {
            tray_base(lid_thickness);
            stack_lip(lid_thickness);
        }
        stack_groove_cut();
    }
}

module label_inlay() {
    front_label();
}

module reference_socket() {
    color([0.12, 0.12, 0.12, 0.75])
        translate([-socket_size[0] / 2, -socket_size[1] / 2, support_z])
            cube([socket_size[0], socket_size[1], socket_height]);
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

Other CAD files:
exports/plcc32-socket-label.stl
exports/plcc32-socket-tray.stl
exports/dip18-tray.stl
exports/dip20-tray.stl
exports/dip14-tray.stl
exports/dip32-tray.stl
exports/dip16-label.stl
plcc44_socket_tray.scad
exports/dip14-fit-test.stl
exports/dip16-fit-test.stl
exports/dip16-tray.stl
exports/dip18-fit-test.stl
exports/dip20-fit-test.stl
exports/dip20-label.stl
exports/dip28-fit-test.stl
exports/dip28-label.stl
exports/dip28-tray.stl
exports/dip32-fit-test.stl
exports/dip32-label.stl
exports/dip40-fit-test.stl
exports/dip40-label.stl

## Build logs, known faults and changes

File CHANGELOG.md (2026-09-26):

# Changelog

All notable changes to this project are documented here. Releases follow
[Semantic Versioning](https://semver.org/).

## [1.4.0] - 2026-09-26

### Added

- A 36-position tray and fit-test coupon for MPE M-PLCC 44 T through-hole
  sockets, using the common stacking interface and lid.
- A slim 300 mil DIP-28 profile with 52 channel positions, plus printable
  tray, label, and fit-test exports.
- Physical fit-test verification for the slim DIP-28 and PLCC44 trays.
- README preview renders for the slim DIP-28 and PLCC44 trays.

## [1.3.0] - 2026-09-05

### Added

- A 49-position tray and fit-test coupon for MPE M-PLCC 32 T through-hole
  sockets, compatible with the existing stacking interface and lid.
- A fit-test-corrected 6 × 8 × 4 mm PLCC32 support island that fits inside
  the socket's bent pins.
- PLCC32 pocket walls raised by 5 mm so their tops are approximately flush
  with the socket body.
- A populated PLCC32 tray preview rendered with the same Blender workflow as
  the existing DIP tray previews.

## [1.2.0] - 2026-09-02

### Added

- Universal lid with the same underside groove and top stacking lip as the
  trays, allowing it to cap a stack or sit between trays.
- Automatic lid STL generation in the build and release bundles.

## [1.1.0] - 2026-08-31

### Changed

- Extended both outer channel guides to meet the perimeter wall, eliminating
  the narrow gaps without changing socket clearance or tray capacity.
- Increased the label size and centered it vertically from the calculated
  wall height.

## [1.0.0] - 2026-08-31

### Added

- Parametric trays for DIP-14, DIP-16, DIP-18, DIP-20, DIP-28, DIP-32, and
  DIP-40 sockets.
- Common stackable tray interface, recessed label inlays, and fit-test
  coupons.
- Retaining guides on both sides of every storage channel, including the two
  channels next to the tray perimeter.
- Versioned release automation with a complete STL archive and SHA-256
  checksums.

[1.4.0]: https://github.com/ifilot/parametric-dip-socket-tray/compare/v1.3.0...v1.4.0
[1.3.0]: https://github.com/ifilot/parametric-dip-socket-tray/compare/v1.2.0...v1.3.0
[1.2.0]: https://github.com/ifilot/parametric-dip-socket-tray/compare/v1.1.0...v1.2.0
[1.1.0]: https://github.com/ifilot/parametric-dip-socket-tray/compare/v1.0.0...v1.1.0
[1.0.0]: https://github.com/ifilot/parametric-dip-socket-tray/releases/tag/v1.0.0

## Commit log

2026-08-31 Fixing edge channels
    [dip14-tray.stl, dip16-tray.stl, dip18-tray.stl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]
2026-08-31 Increasing label and filling gap
    [dip14-label.stl, dip14-tray.stl, dip16-label.stl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]
2026-09-02 Adding lid
    [dip-socket-tray-lid.stl, dip_socket_tray.scad]
2026-09-05 Creating PLCC32 tray
    [plcc32-socket-fit-test.stl, plcc32-socket-label.stl, plcc32-socket-tray.stl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]
2026-09-26 Add slim DIP-28 and PLCC44 trays
    [dip28-slim-fit-test.stl, dip28-slim-label.stl, dip28-slim-tray.stl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]

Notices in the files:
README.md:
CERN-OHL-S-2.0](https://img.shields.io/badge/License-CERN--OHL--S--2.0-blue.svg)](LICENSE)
